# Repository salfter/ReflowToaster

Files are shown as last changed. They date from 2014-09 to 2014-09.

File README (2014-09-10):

This is a re-creation in KiCad of this project:

https://upverter.com/salfter/129531d44b9b2c59/ReflowToaster2/

which also depends on this project:

https://upverter.com/salfter/f2bd7fd7ccbdb49b/DuinoModSingle/

It's a single-board mashup of the Rocket Scream reflow controller shield and
an Arduino Leonardo:

http://www.rocketscream.com/shop/reflow-oven-controller-shield-arduino-compatible
http://arduino.cc/en/Main/arduinoBoardLeonardo

As such, I anticipate that the Rocket Scream software should run on this
with little or no modification:

https://github.com/rocketscream/Reflow-Oven-Controller

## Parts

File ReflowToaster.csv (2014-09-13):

Quantity | Vendor P/N | Reference | Value | Manufacturer | Manufacturer P/N
1 | 102-1285-ND | B1 | SPEAKER | CUI | CX-0905C
1 | 1253-1084-1-ND | X1 | 16MHz | AVX | PBRC16.00HR70X000
1 | 296-13496-1-ND | U5 | 74LVC2G34 | Texas Instruments | SN74LVC2G34DBVR
1 | 296-16843-1-ND | U6 | 74LVC1T45 | Texas Instruments | SN74LVC1T45DBVR
1 | 3319P-103-ND | R6 | 10k | Bourns | 3319P-1-103
1 | 399-1234-1-ND | C13 | 0.01uF | Kemet | C1206C103K5RACTU
7 | 399-1249-1-ND | C10 C11 C12 C2 C3 C4 C9 | 0.1uF | Kemet | C1206C104K5RACTU
3 | 399-8147-1-ND | C1 C5 C6 | 1uF | Kemet | C1206C105K5RACTU
2 | 490-1060-1-ND | L2 L3 | INDUCTOR_SMALL | Murata | BLM41PG471SN1L
2 | 568-1741-1-ND | Q2 Q3 | PMBT3904 | NXP | PMBT3904
2 | 609-4613-1-ND | J2 J3 | USB-Micro-B | FCI | 10118192-0001LF
1 | 952-2120-ND | P1 | CONN_02X03 | Harwin | M20-9980345
1 | 952-2380-ND | J4 | CONN_02X05 | Harwin | M20-9980545
1 | A98076-ND | J7 | CONN_01X02 | TE Connectivity | 282836-2
1 | ATMEGA32U4-AURCT-ND | U1 | ATMEGA32U4-A | Atmel | ATMEGA32U4-AU
2 | CG0603MLC-05ECT-ND | VR1 VR2 | VR | Bourns | CG0603MLC-05E
1 | FDN340PCT-ND | Q1 | FDN340P | Fairchild | FDN340P
1 | MAX31855KASA+TCT-ND | U7 | MAX31855KASA+ | Maxim | MAX31855KASA+
1 | MCP1700T3302ETTCT-ND | U2 | MCP1700T-3302E/TT | Microchip | MCP1700T-3302E/TT
1 | MF-MSMF050-2CT-ND | F1 | 500mA | Bourns | MF-MSMF050-2
1 | MH2029-300YCT-ND | L1 | Ferrite Bead | Bourns | MH2029-300Y
1 | NHD-0208AZ-FL-YBW-ND | U3 | LCD8X2 | Newhaven Display | NHD-0208AZ-FL-YBW
1 | NUP2105LT1GOSCT-ND | U8 | NUP2105L | ON Semiconductor | NUP2105LT1G
3 | P10KECT-ND | R10 R3 R4 | 10k | Panasonic | ERJ-8GEYJ103V
1 | P1.0KECT-ND | R5 | 1k | Panasonic | ERJ-8GEYJ102V
2 | P10KECT-ND | R7 R9 | 10k | Panasonic | ERJ-8GEYJ103V
2 | P22ECT-ND | R1 R2 | 22 | Panasonic | ERJ-8GEYJ220V
1 | P47KECT-ND | R8 | 47k | Panasonic | ERJ-8GEYJ473V
1 | S7076-ND | U3a |  | Sullins | PPTC082LFBN-RC
1 | 952-1817-ND | U3b |  | Harwin | M20-9760842

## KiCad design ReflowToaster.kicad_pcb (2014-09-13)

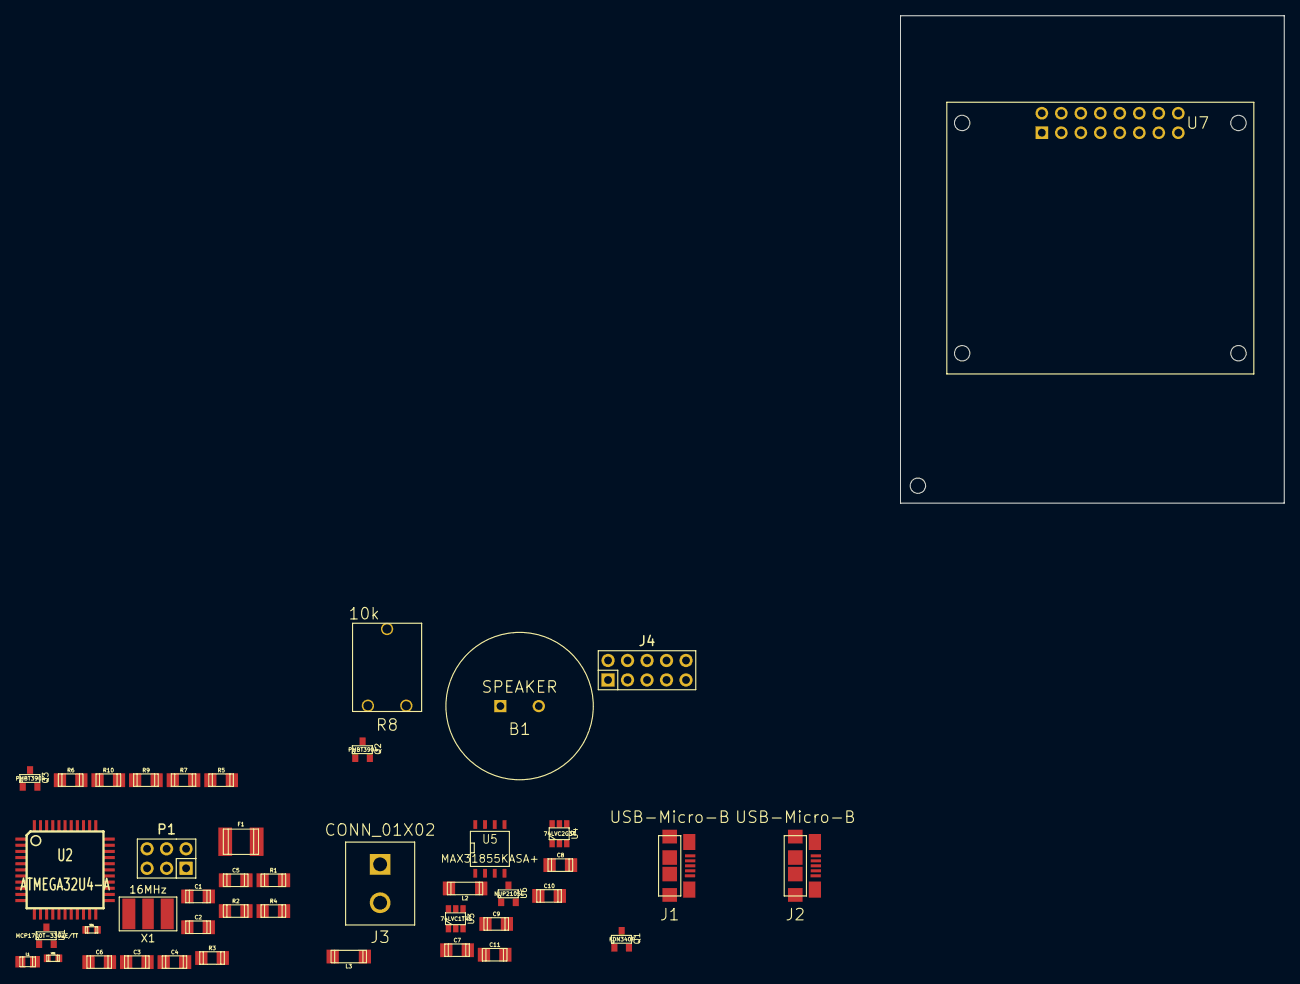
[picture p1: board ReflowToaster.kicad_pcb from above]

Board: 2 copper layers, 50.0 x 63.5 mm, 45 parts (0 on the bottom side), 47 nets, no tracks yet.

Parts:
B1: SPEAKER; CX-0905C
C1, C2, C3: 1uF; c_1206
C4, C5, C6, C7, C8, C9, C10: 0.1uF; c_1206
C11: 0.01uF; c_1206
F1: 500mA; c_1812
J1, J2: USB-Micro-B; FCI_10118192-0001LF
J3: CONN_01X02; 282836-2
J4: CONN_02X05; Pin_Header_Straight_2x05
L1: Ferrite Bead; c_0805
L2, L3: INDUCTOR_SMALL; smd_1806
MH: MountingHole_2mm
P1: CONN_02X03; Socket_Strip_Straight_2x03
Q1: FDN340P
Q2, Q3: PMBT3904; SOT-23
R1, R2: 22; c_1206
R3, R4, R5, R6, R9: 10k; c_1206
R7: 1k; c_1206
R8: 10k; 3319P-1-103
R10: 47k; c_1206
U1: MCP1700T-3302E/TT; SOT-23
U2: ATMEGA32U4-A; TQFP-44
U3: 74LVC1T45; SOT-23-6
U4: 74LVC2G34; SOT-23-6
U5: MAX31855KASA+; SOIC-8-N
U6: NUP2105L; SOT-23
U7: LCD8X2; LCD_8x2
VR1, VR2: VR; c_0603
X1: 16MHz; AVX_PBRC-H

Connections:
+3.3V: C2.1, C8.1, C9.1, C10.1, U1.2, U3.6, U5.4
+5V: B1.1, C1.1, C5.1, C7.1, F1.2, J4.1, J4.3, L1.1, P1.2, R4.1, R5.1, R8.1, U1.3, U2.2, U2.7, U2.14, U2.34, U2.44, U3.1, U7.2, U7.15
/DuinoModSingle/4/A6: R7.2, U2.25
/DuinoModSingle/5/PWM: R10.2, U2.31
/DuinoModSingle/6/PWM/A8: R9.2, U2.27
/DuinoModSingle/7: U2.1, U7.4
/DuinoModSingle/8/A9: U2.28, U7.6
/DuinoModSingle/9/PWM/A10: U2.29, U7.11
/DuinoModSingle/10/PWM/A11: U2.30, U7.12
/DuinoModSingle/11/PWM: U2.12, U7.13
/DuinoModSingle/12/A7: U2.26, U7.14
/DuinoModSingle/A1: U2.37, U4.1
/DuinoModSingle/A2: U2.38, U4.3
/DuinoModSingle/A3: U2.39, U3.3
/DuinoModSingle/AREF: C4.1, U2.42
/DuinoModSingle/MISO: P1.1, U2.11
/DuinoModSingle/MOSI: P1.4, U2.10
/DuinoModSingle/SCK: P1.3, U2.9
/DuinoModSingle/USB_5V: F1.1, Q1.S
/DuinoModSingle/USB_D+: J2.3, R2.2, VR2.1
/DuinoModSingle/USB_D-: J2.2, R1.2, VR1.1
/DuinoModSingle/~RESET: J4.10, P1.5, R4.2, U2.13
BTN1: J4.6, R5.2, R6.1, U2.36
BTN2: J4.8, R6.2
GND: C1.2, C2.2, C3.2, C4.2, C5.2, C6.2, C7.2, C8.2, C9.2, C10.2, J1.4, J1.5, J1.6, J1.7, J1.8, J1.9, J1.10, J1.11, J2.4, J2.5, J2.6, J2.7, J2.8, J2.9, J2.10, J2.11, J4.5, J4.7, J4.9, P1.6, Q2.2, Q3.2, R3.1, R8.2, U1.1, U2.5, U2.15, U2.23, U2.35, U2.43, U3.2, U3.5, U4.2, U5.1, U6.3, U7.1, U7.5, U7.16, VR1.2, VR2.2, X1.3
LED: J4.2, R7.1
unnamed: B1.2, Q2.3
unnamed: C3.1, U2.6
unnamed: C6.1, L1.2, U2.24
unnamed: C11.1, L2.1, U5.3, U6.2
unnamed: C11.2, L3.1, U5.2, U6.1
unnamed: J1.1, Q1.G
unnamed: J2.1, Q1.D
unnamed: J3.1, L2.2
unnamed: J3.2, L3.2
unnamed: Q2.1, R9.1
unnamed: Q3.1, R10.1
unnamed: R1.1, U2.3
unnamed: R2.1, U2.4
unnamed: R3.2, U2.33
unnamed: R8.3, U7.3
unnamed: U2.16, X1.2
unnamed: U2.17, X1.1
unnamed: U3.4, U5.7
unnamed: U4.4, U5.6
unnamed: U4.6, U5.5
SSR: J4.4, Q3.3

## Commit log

2014-09-09 schematic closer to complete
    [DuinoModSingle.sch, ReflowToaster.sch]
2014-09-09 add footprint for resonator
    [DuinoModSingle.sch]
2014-09-09 DuinoModSingle complete
    [DuinoModSingle.sch, ReflowToaster.sch]
2014-09-09 more changes
    [DuinoModSingle.sch, ReflowToaster.sch]
2014-09-10 add footprint for USB connectors
    [DuinoModSingle.sch, ReflowToaster.sch]
2014-09-10 add FDN340P
    [DuinoModSingle.sch, ReflowToaster.sch]
2014-09-10 add MAX31855
    [DuinoModSingle.sch, ReflowToaster.sch]
2014-09-10 new sheet
    [Thermocouple.sch]
2014-09-10 more components added
    [DuinoModSingle.sch, ReflowToaster.sch, Thermocouple.sch]
2014-09-10 working on thermocouple section now
    [Thermocouple.sch]
2014-09-10 thermocouple section complete
    [DuinoModSingle.sch, ReflowToaster.sch, Thermocouple.sch]
2014-09-11 schematic complete
    [DuinoModSingle.sch, Interface.sch, ReflowToaster.sch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]
2014-09-11 add part info for speaker
    [DuinoModSingle.sch, Interface.sch, ReflowToaster.sch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]
2014-09-11 DuinoModSingle & main sheet tagged with vendor part #s for BOM generation
    [DuinoModSingle.sch, ReflowToaster.sch]
2014-09-11 remove some extra whitespace
    [DuinoModSingle.sch]
2014-09-12 add BOM generator script
2014-09-12 last of the new footprints added; PCB started
    [DuinoModSingle.sch, Interface.sch, ReflowToaster.kicad_pcb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]
2014-09-12 components tagged with vendor part IDs
    [Interface.sch, ReflowToaster.csv, ReflowToaster.sch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]
2014-09-13 fix incorrect vendor part number
    [Interface.sch, ReflowToaster.csv]
2014-09-13 redo annotation
    [DuinoModSingle.sch, Interface.sch, ReflowToaster.sch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]
2014-09-13 more work
    [Interface.sch, ReflowToaster.kicad_pcb]
2014-09-15 don't need extra-components file anymore
    [extra-components.csv]
